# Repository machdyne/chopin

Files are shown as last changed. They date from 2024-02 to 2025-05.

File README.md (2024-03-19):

# Chopin Motherboard

Chopin is a host board that when paired with a [Sechzig](https://github.com/machdyne/sechzig) compute module can function as a development board.

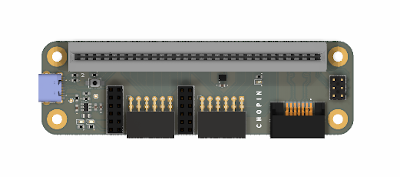
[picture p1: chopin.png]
Chopin


This repo contains schematics, PCB layouts, pinouts and documentation.

Find more information on the [Chopin product page](https://machdyne.com/product/chopin-motherboard/).

## Using Chopin

Chopin requires a Sechzig module to function. **When inserting a Sechzig module, make sure that pin 2 on Chopin and pin 2 on the module are both on the same side.**

## Programming

Chopin has a JTAG header that when paired with a JTAG programmer, can be used to program Sechzig modules. The following examples assume you're using a USB Blaster JTAG programmer.

Program the configuration SRAM of a Sechzig module:

```
sudo openFPGALoader -c usb-blaster image.bit
```

Program the configuration flash on a Sechzig module:

```
sudo openFPGALoader -f -c usb-blaster image.bit
```

## Pinouts

### JTAG Header

The 3.3V JTAG header can be used to program the Sechzig module. It can also be used to provide power (5V) to the board.

```
6 5
4 3
2 1
```

| Pin | Signal |
| --- | --- |
| 1 | TCK |
| 2 | TDI |
| 3 | TDO |
| 4 | TMS |
| 5 | 5V0 |
| 6 | GND |

### LVDS Port

Chopin has an experimental SATA-style LVDS port. SATA is not supported.

| Pin | Signal |
| --- | --- |
| 1 | GND |
| 2 | DS2\_P |
| 3 | DS2\_N |
| 4 | GND |
| 5 | DS1\_P |
| 6 | DS1\_N |
| 7 | GND |

## Funding

This project was partially funded through the NGI0 Entrust Fund, a fund established by NLnet with financial support from the European Commission's Next Generation Internet programme.

## License

This project is released under the [CERN-OHL-P](LICENSE.txt) license.

Note: You can use these designs for commercial purposes but we ask that instead of producing exact clones, that you either replace our trademarks and logos with your own or add your own next to ours.

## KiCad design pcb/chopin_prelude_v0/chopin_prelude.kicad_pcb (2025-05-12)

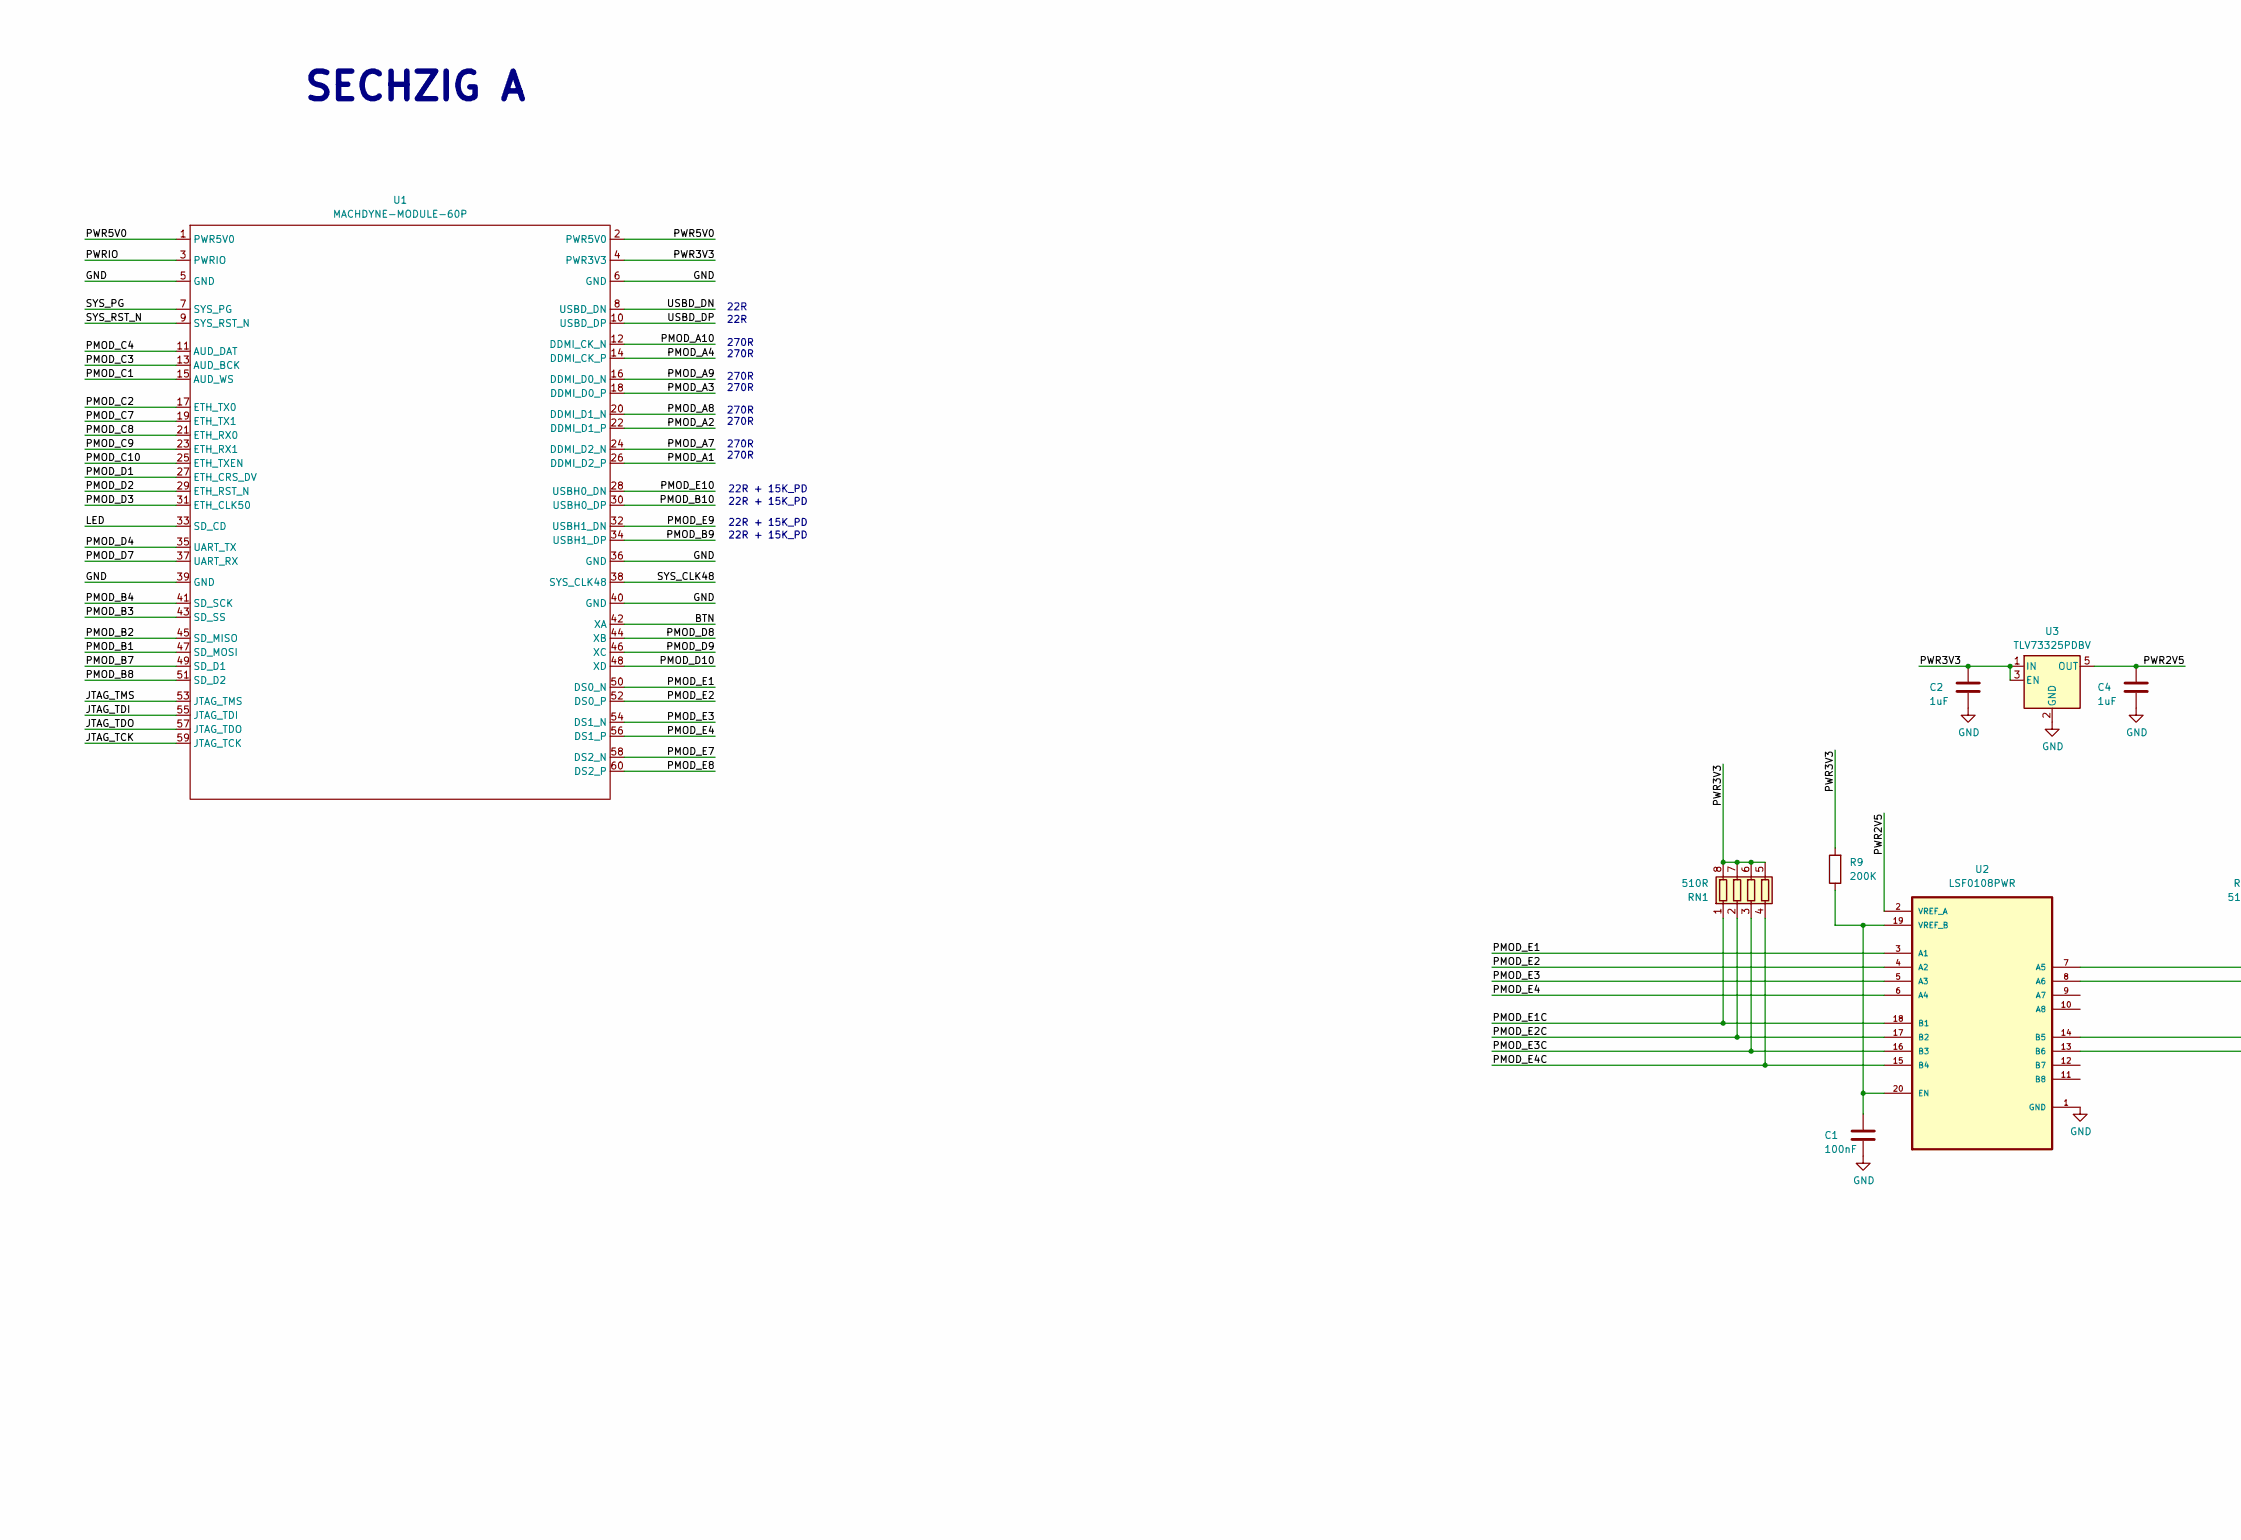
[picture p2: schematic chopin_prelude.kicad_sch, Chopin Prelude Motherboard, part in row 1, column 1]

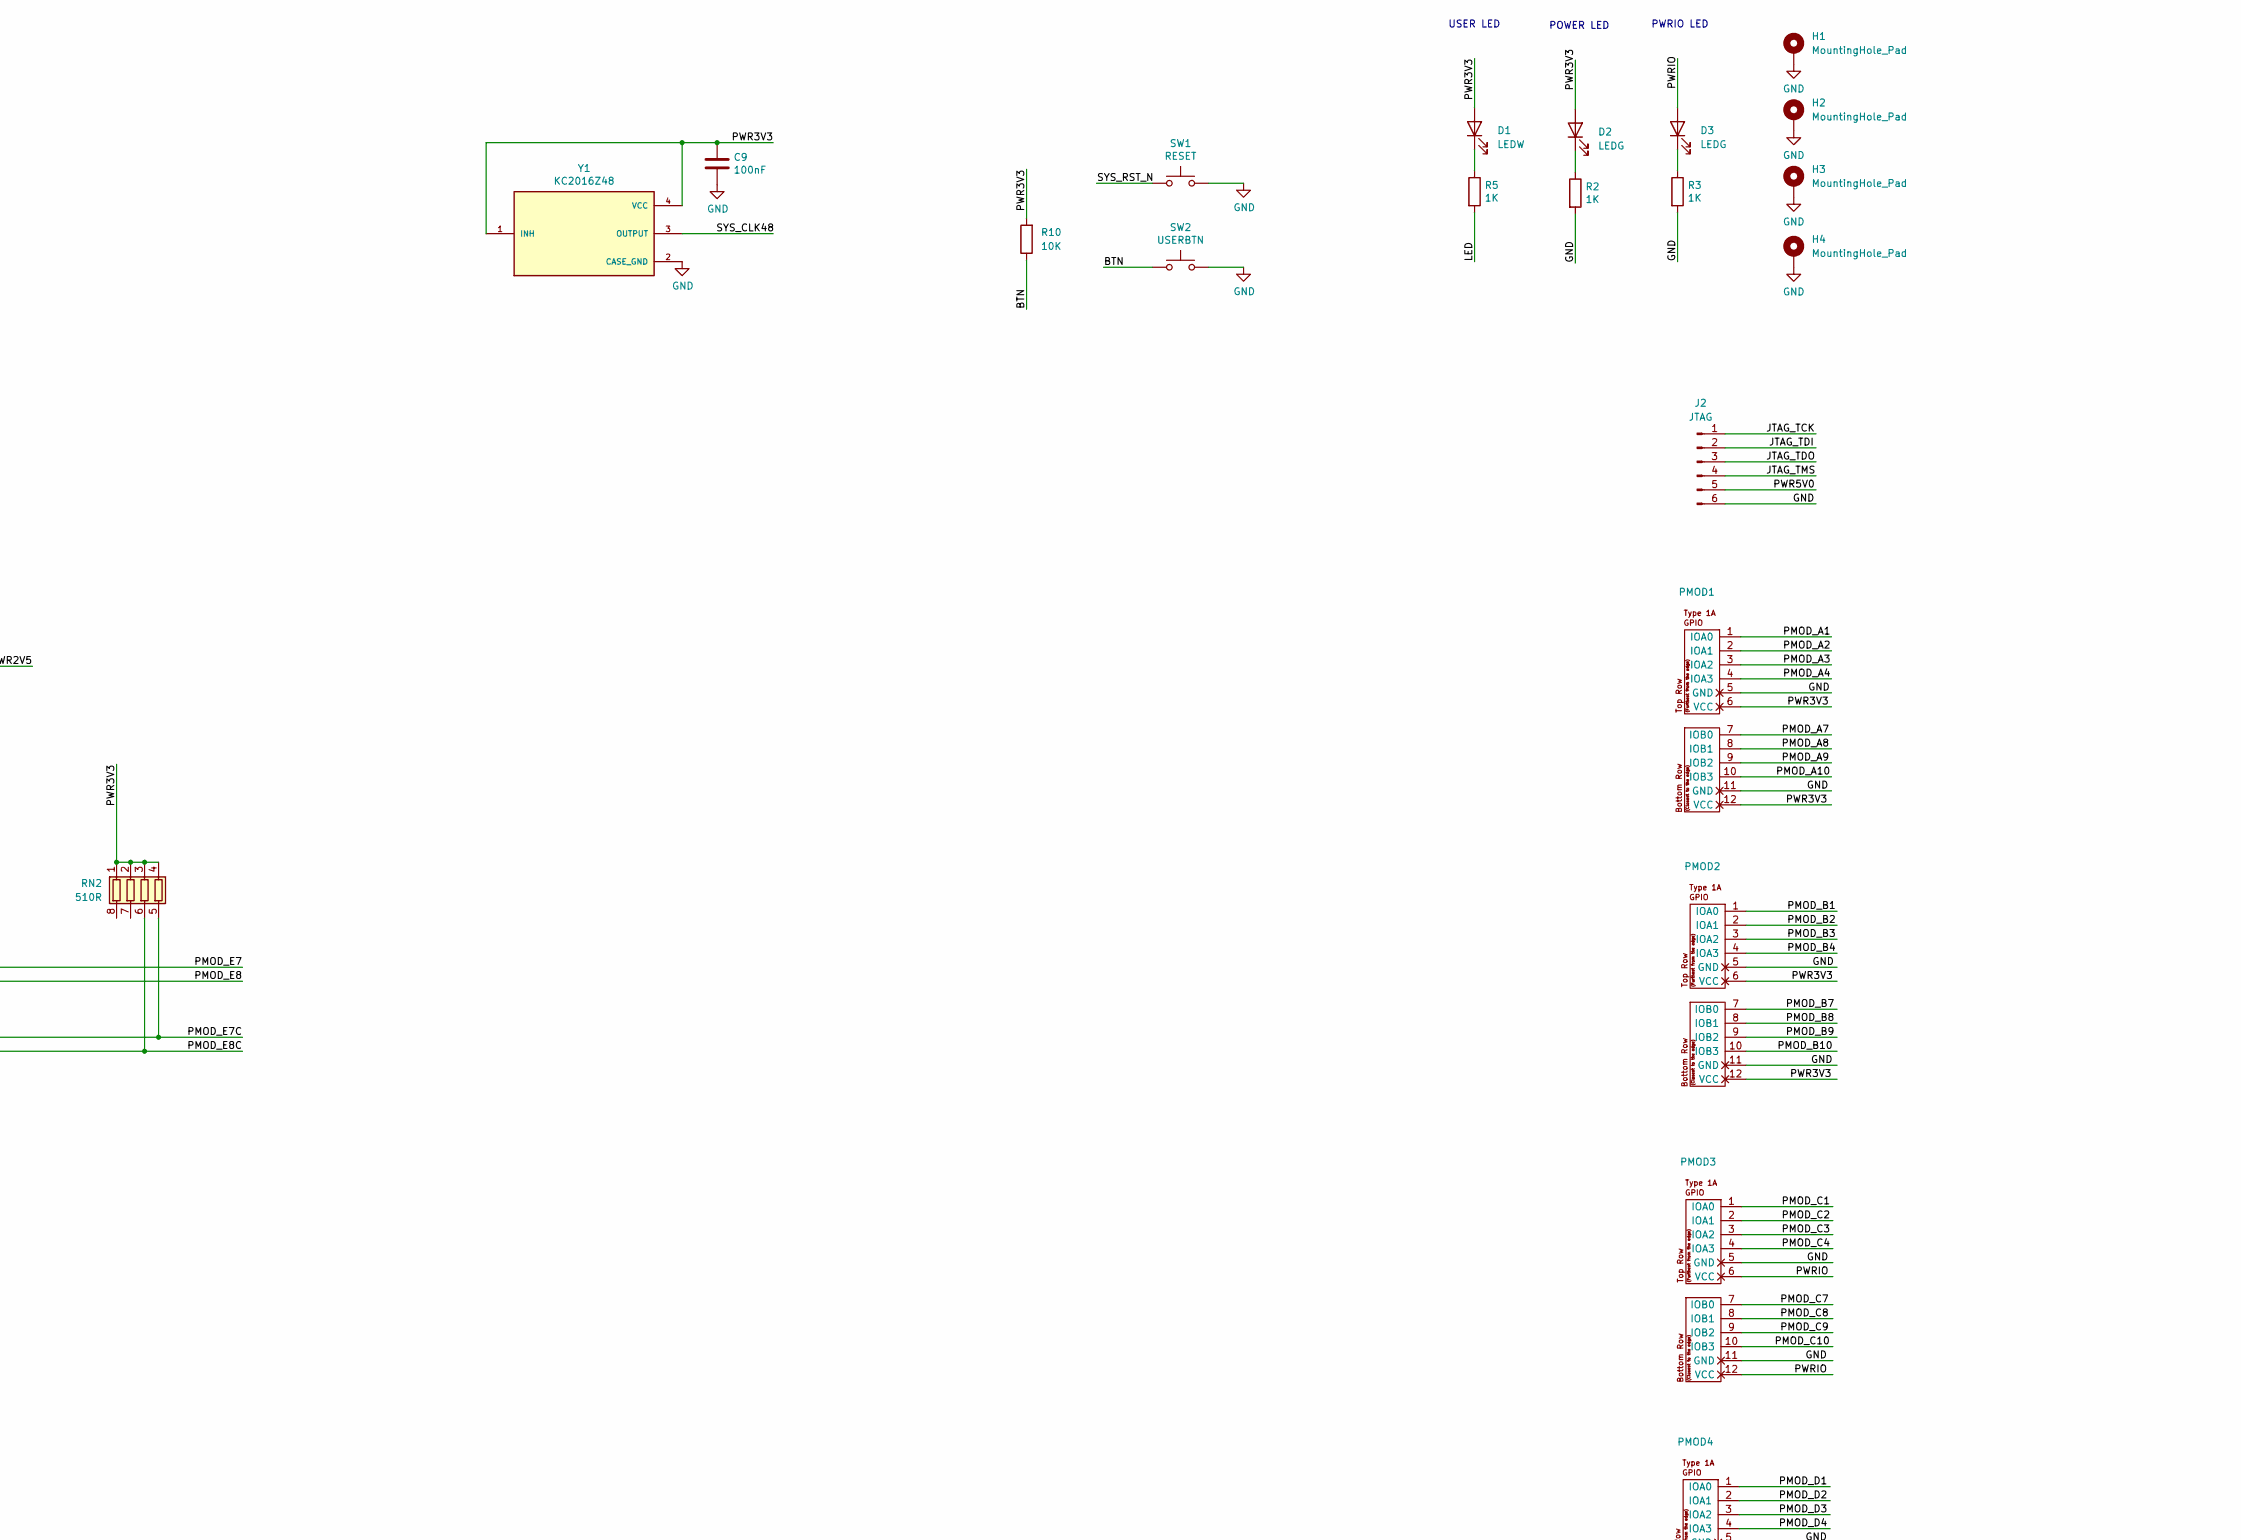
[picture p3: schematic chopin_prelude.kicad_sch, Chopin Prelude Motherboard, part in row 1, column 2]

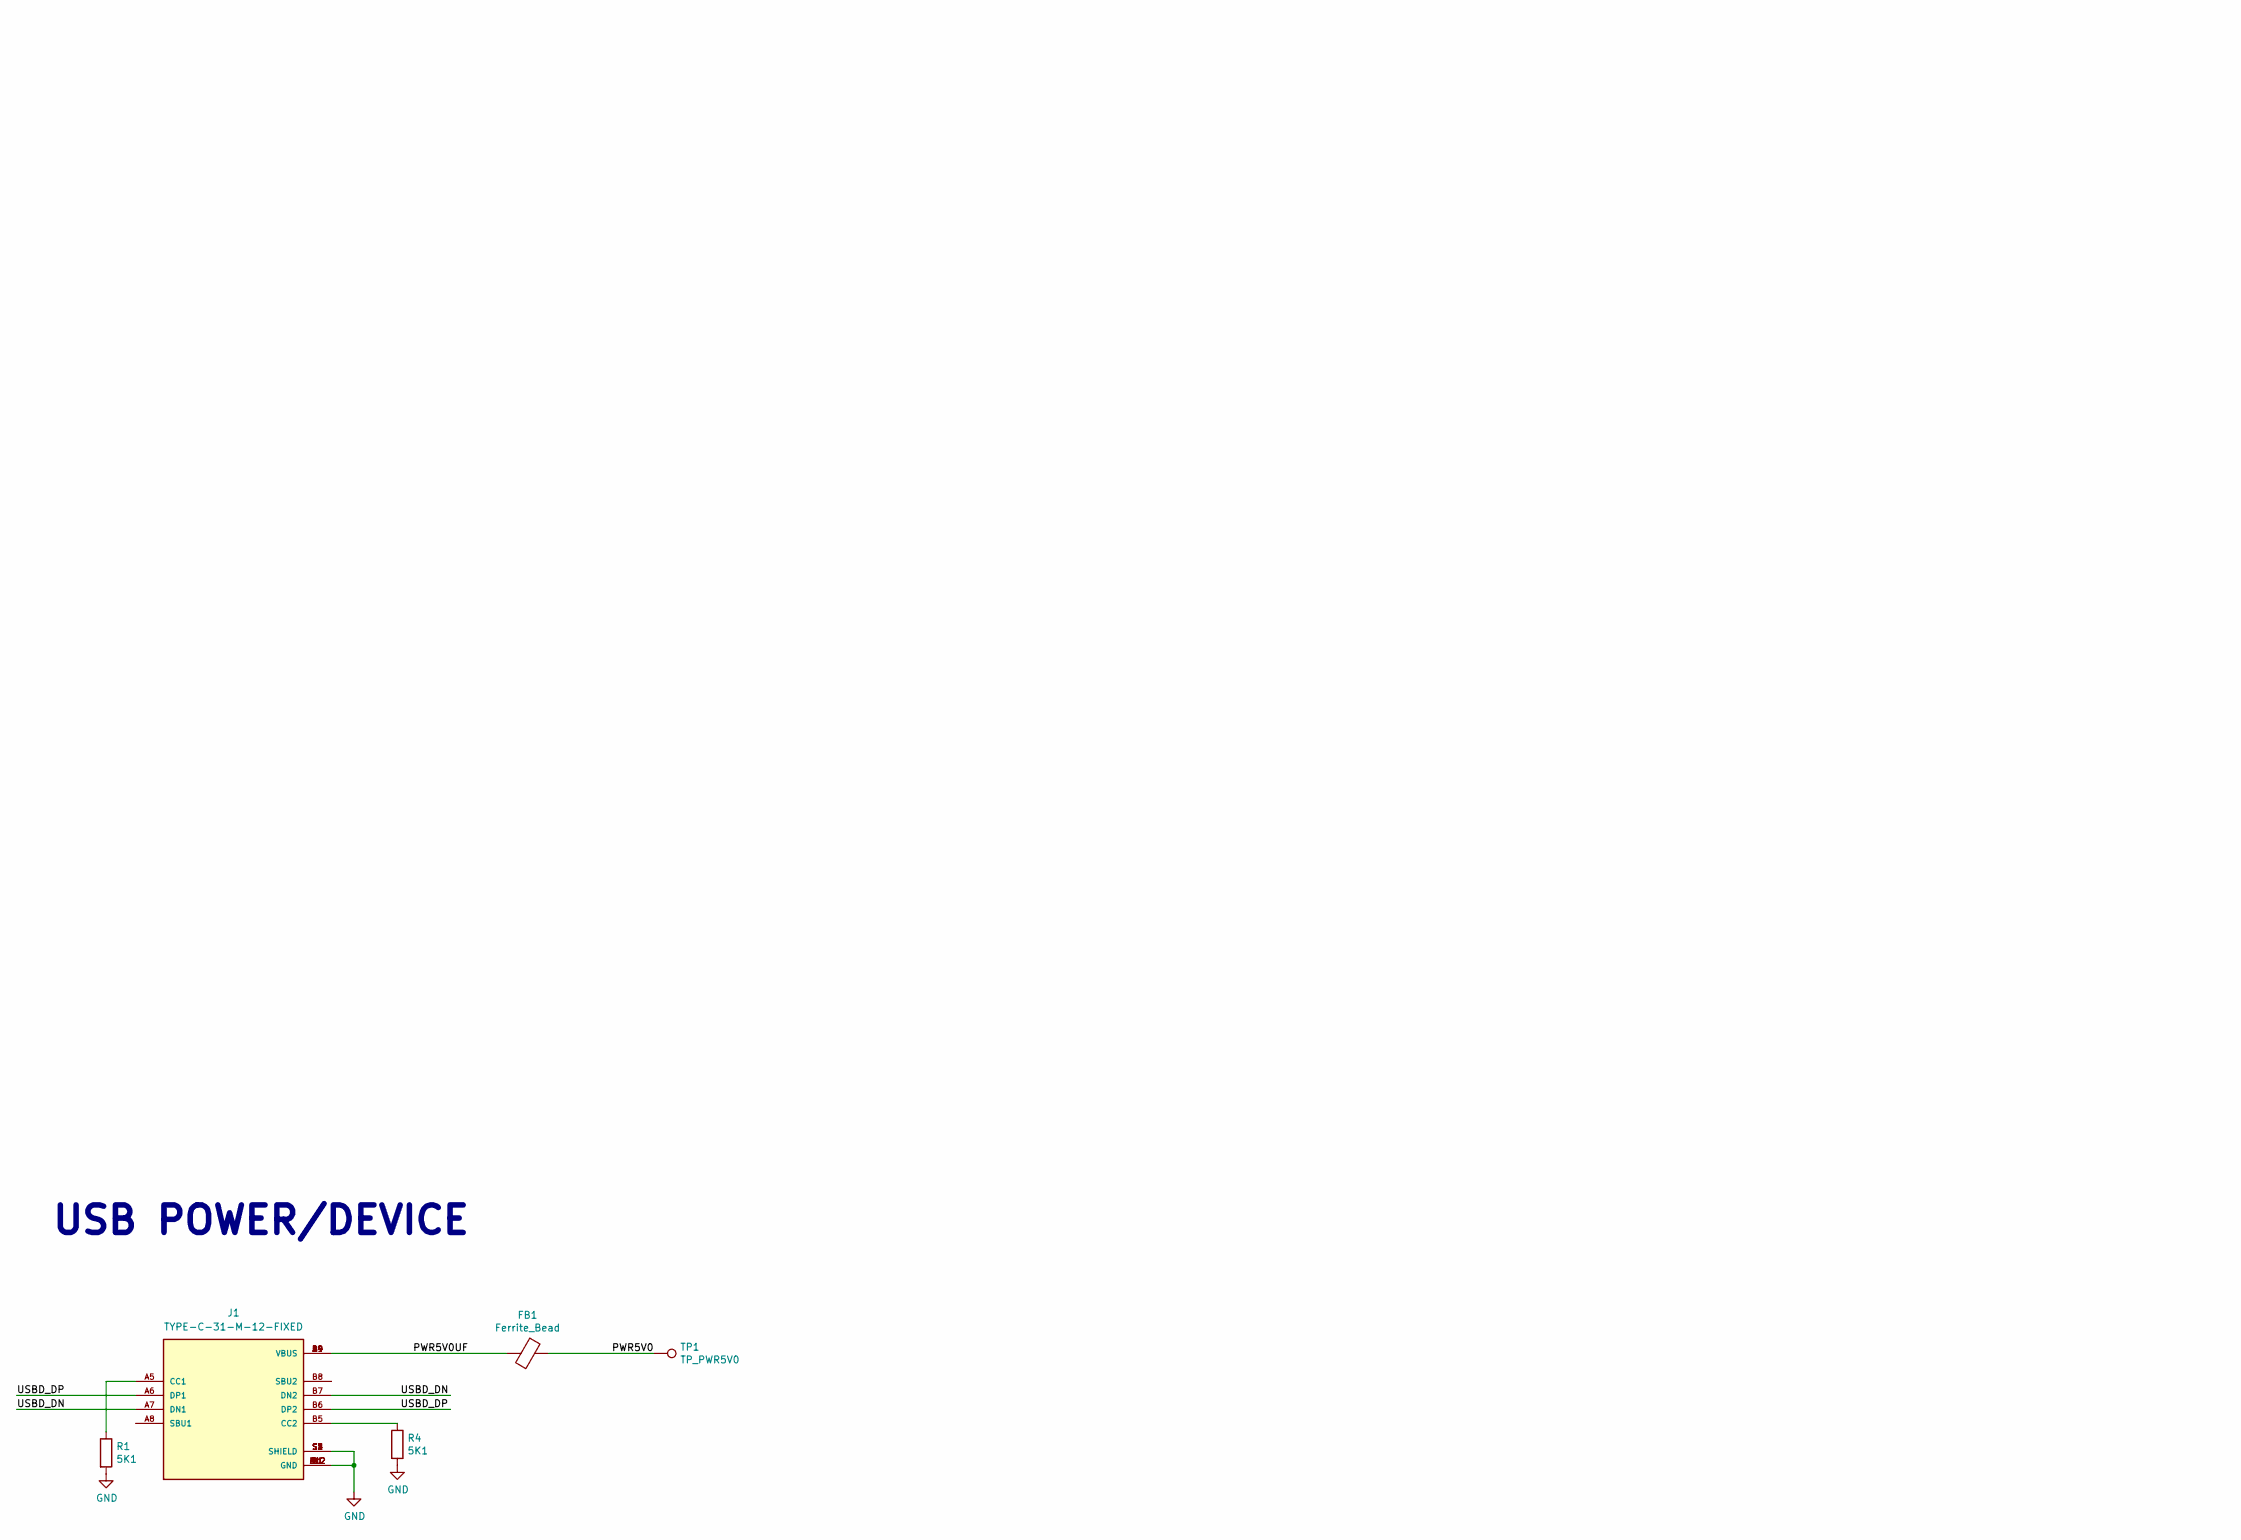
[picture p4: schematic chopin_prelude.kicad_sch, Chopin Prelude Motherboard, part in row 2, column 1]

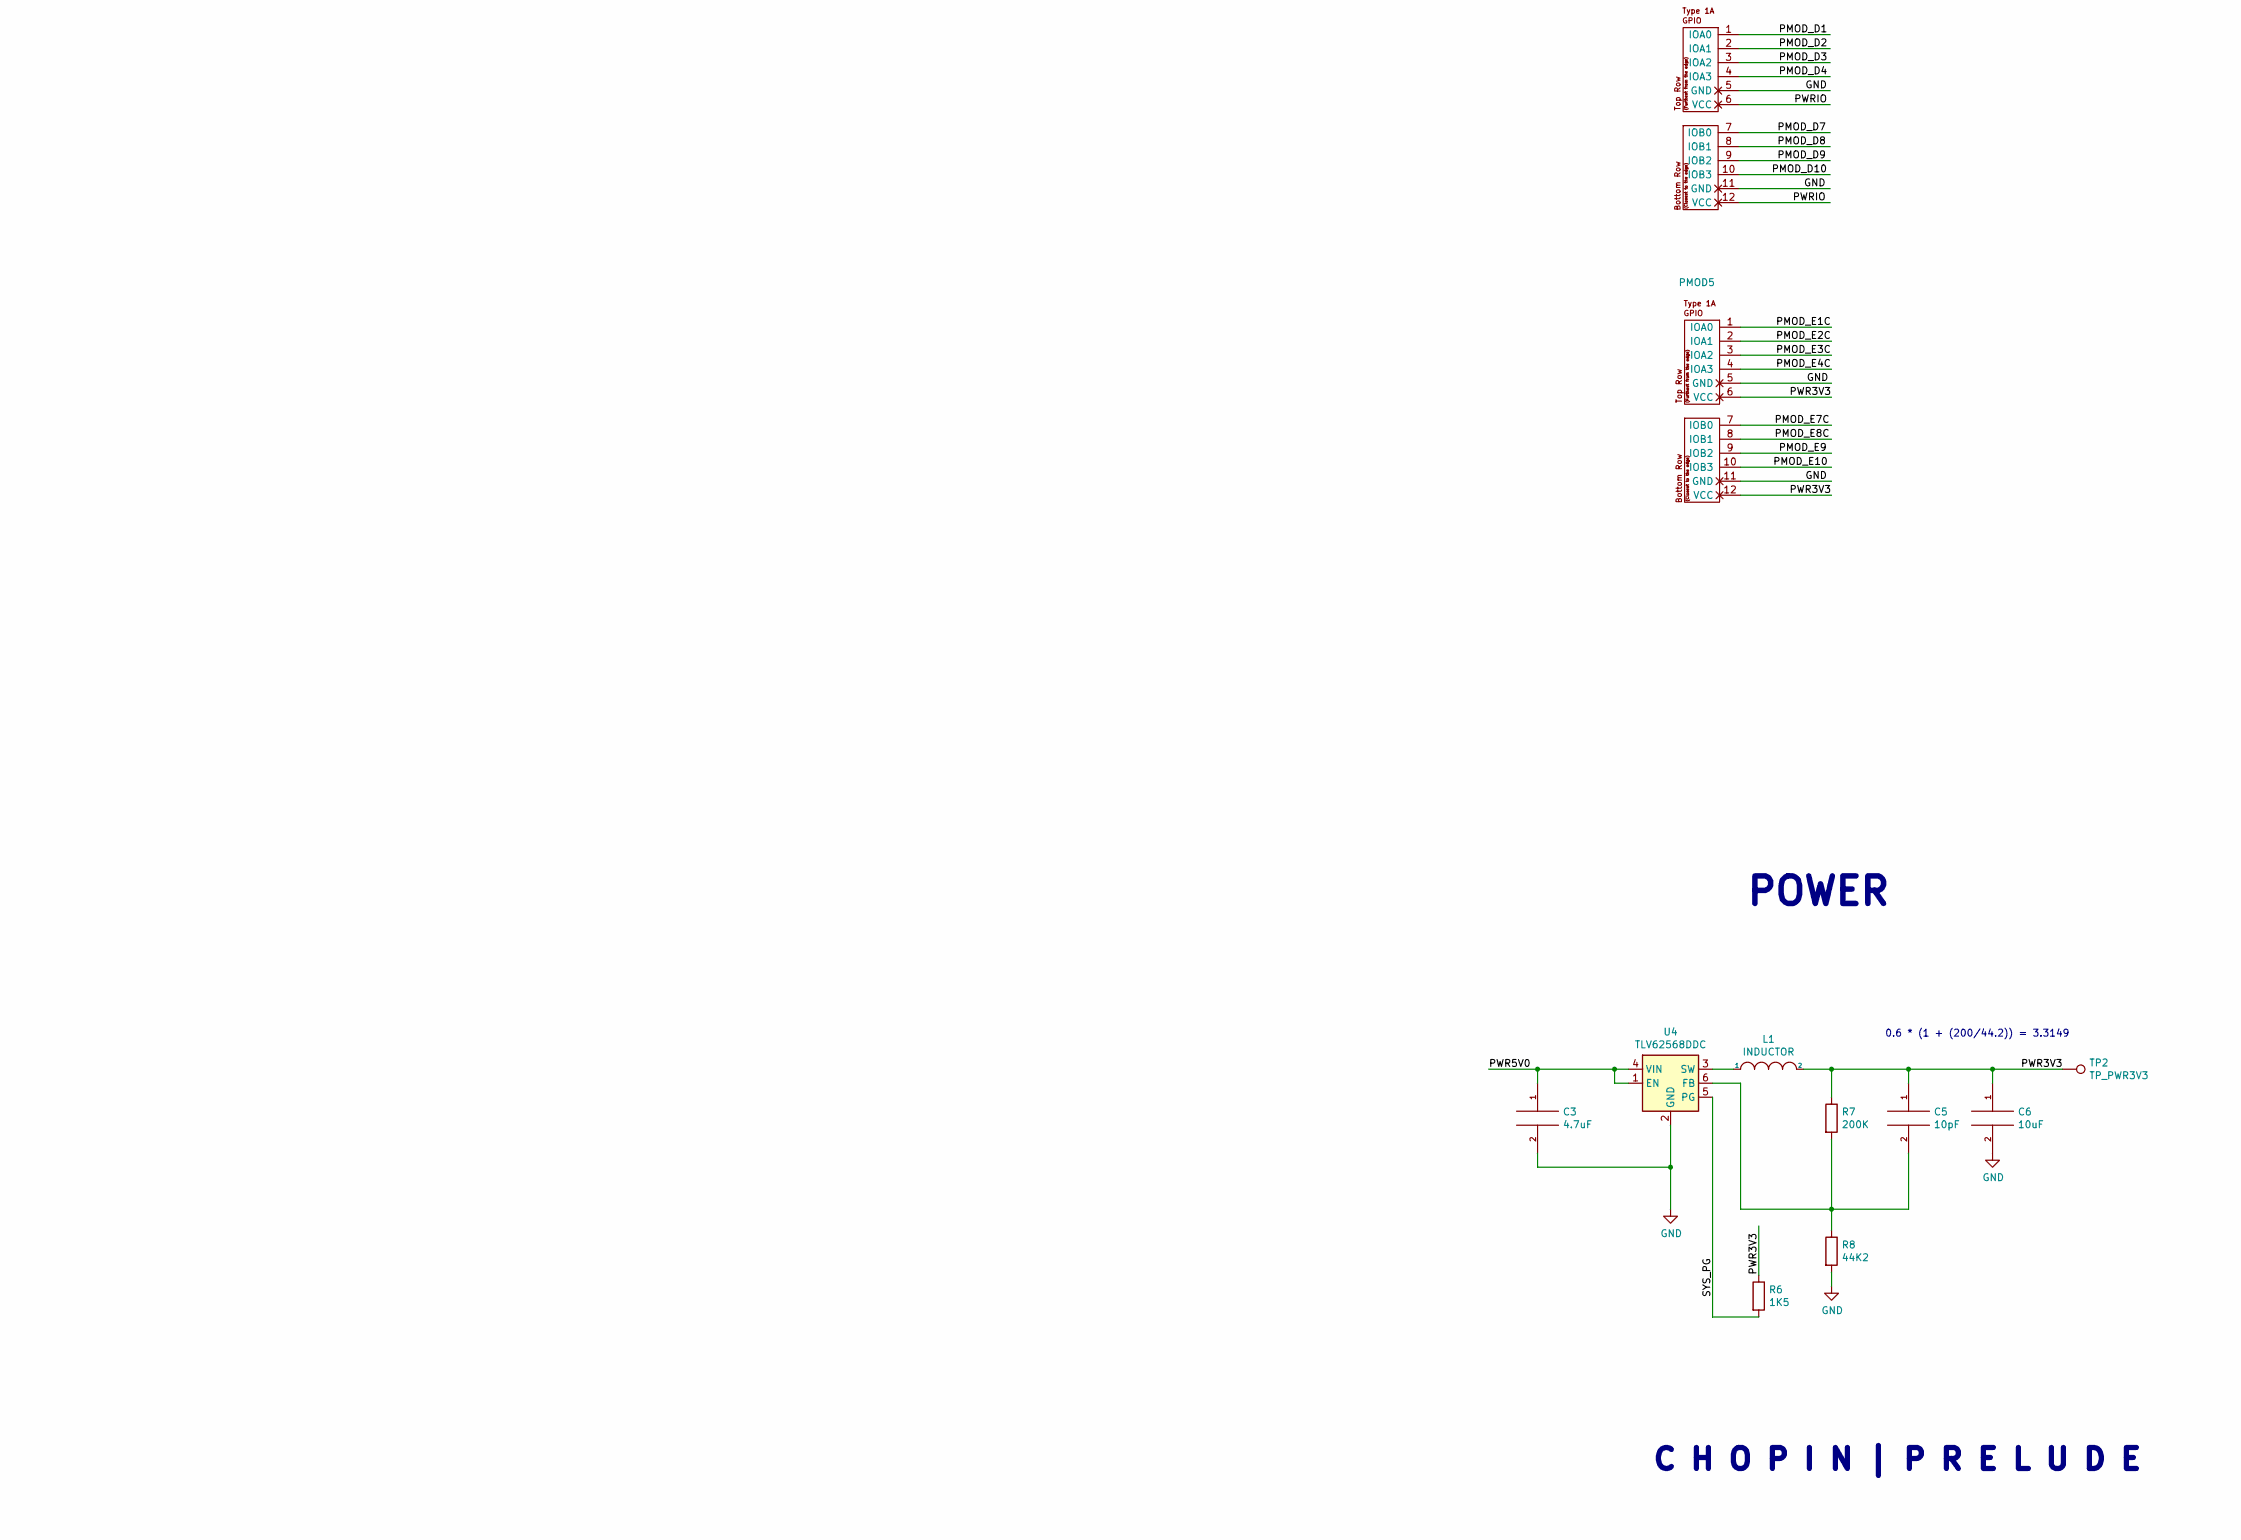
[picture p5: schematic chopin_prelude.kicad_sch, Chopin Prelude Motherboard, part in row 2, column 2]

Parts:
C1: 100nF; C_0402_1005Metric
C2, C4: 1uF; C_0402_1005Metric
C3: 4.7uF; C_0603_1608Metric
C5: 10pF; C_0603_1608Metric
C6: 10uF; C_0603_1608Metric
C9: 100nF; C_0603_1608Metric
D1: LEDW; LED_0603_1608Metric
D2, D3: LEDG; LED_0603_1608Metric
FB1: Ferrite_Bead; R_0603_1608Metric
H1, H2, H3, H4: MountingHole_Pad; MountingHole_3.2mm_M3_Pad
J1: TYPE-C-31-M-12-FIXED; USB_C_Receptacle_HRO_TYPE-C-31-M-12-BIG-PADS; PARTREV A
J2: JTAG; PinHeader_2x03_P2.54mm_Vertical
L1: INDUCTOR; L_0805_2012Metric
PMOD1, PMOD2, PMOD5: PMOD-Device-x2-Type-1A-GPIO; PMOD_2x06_HOST
PMOD3, PMOD4: PMOD-Device-x2-Type-1A-GPIO; PMOD_2x06_HOST_VERTICAL
R1, R4: 5K1; R_0603_1608Metric
R2, R3, R5: 1K; R_0603_1608Metric
R6: 1K5; R_0603_1608Metric
R7: 200K; R_0603_1608Metric
R8: 44K2; R_0603_1608Metric
R9: 200K; R_0402_1005Metric
R10: 10K; R_0603_1608Metric
RN1, RN2: 510R; R_Array_Convex_4x0402
SW1: RESET; Button_2P_3x4mm
SW2: USERBTN; Kailh_Mute_6x6mm
TP1: TP_PWR5V0; TestPoint_THTPad_D1.0mm_Drill0.5mm
TP2: TP_PWR3V3; TestPoint_THTPad_D1.0mm_Drill0.5mm
U1: MACHDYNE-MODULE-60P; MACHDYNE_EDGE_SOCKET_60P
U2: LSF0108PWR; TSSOP-20_4.4x6.5mm_P0.65mm
U3: TLV73325PDBV; SOT-23-5
U4: TLV62568DDC; SOT-23-6
Y1: KC2016Z48; OSC_KC2016Z13.5600C1KX00; PARTREV November 2020

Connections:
/BTN: R10.1, SW2.1, U1.42 (XA)
/JTAG_TCK: J2.1, U1.59 (JTAG_TCK)
/JTAG_TDI: J2.2, U1.55 (JTAG_TDI)
/JTAG_TDO: J2.3, U1.57 (JTAG_TDO)
/JTAG_TMS: J2.4, U1.53 (JTAG_TMS)
/LED: R5.2, U1.33 (SD_CD)
/PMOD_A1: PMOD1.1 (IOA0), U1.26 (DDMI_D2_P)
/PMOD_A2: PMOD1.2 (IOA1), U1.22 (DDMI_D1_P)
/PMOD_A3: PMOD1.3 (IOA2), U1.18 (DDMI_D0_P)
/PMOD_A4: PMOD1.4 (IOA3), U1.14 (DDMI_CK_P)
/PMOD_A7: PMOD1.7 (IOB0), U1.24 (DDMI_D2_N)
/PMOD_A8: PMOD1.8 (IOB1), U1.20 (DDMI_D1_N)
/PMOD_A9: PMOD1.9 (IOB2), U1.16 (DDMI_D0_N)
/PMOD_A10: PMOD1.10 (IOB3), U1.12 (DDMI_CK_N)
/PMOD_B1: PMOD2.1 (IOA0), U1.47 (SD_MOSI)
/PMOD_B2: PMOD2.2 (IOA1), U1.45 (SD_MISO)
/PMOD_B3: PMOD2.3 (IOA2), U1.43 (SD_SS)
/PMOD_B4: PMOD2.4 (IOA3), U1.41 (SD_SCK)
/PMOD_B7: PMOD2.7 (IOB0), U1.49 (SD_D1)
/PMOD_B8: PMOD2.8 (IOB1), U1.51 (SD_D2)
/PMOD_B9: PMOD2.9 (IOB2), U1.34 (USBH1_DP)
/PMOD_B10: PMOD2.10 (IOB3), U1.30 (USBH0_DP)
/PMOD_C1: PMOD3.1 (IOA0), U1.15 (AUD_WS)
/PMOD_C2: PMOD3.2 (IOA1), U1.17 (ETH_TX0)
/PMOD_C3: PMOD3.3 (IOA2), U1.13 (AUD_BCK)
/PMOD_C4: PMOD3.4 (IOA3), U1.11 (AUD_DAT)
/PMOD_C7: PMOD3.7 (IOB0), U1.19 (ETH_TX1)
/PMOD_C8: PMOD3.8 (IOB1), U1.21 (ETH_RX0)
/PMOD_C9: PMOD3.9 (IOB2), U1.23 (ETH_RX1)
/PMOD_C10: PMOD3.10 (IOB3), U1.25 (ETH_TXEN)
/PMOD_D1: PMOD4.1 (IOA0), U1.27 (ETH_CRS_DV)
/PMOD_D2: PMOD4.2 (IOA1), U1.29 (ETH_RST_N)
/PMOD_D3: PMOD4.3 (IOA2), U1.31 (ETH_CLK50)
/PMOD_D4: PMOD4.4 (IOA3), U1.35 (UART_TX)
/PMOD_D7: PMOD4.7 (IOB0), U1.37 (UART_RX)
/PMOD_D8: PMOD4.8 (IOB1), U1.44 (XB)
/PMOD_D9: PMOD4.9 (IOB2), U1.46 (XC)
/PMOD_D10: PMOD4.10 (IOB3), U1.48 (XD)
/PMOD_E1: U1.50 (DS0_N), U2.3 (A1)
/PMOD_E1C: PMOD5.1 (IOA0), RN1.1 (R1.1), U2.18 (B1)
/PMOD_E2: U1.52 (DS0_P), U2.4 (A2)
/PMOD_E2C: PMOD5.2 (IOA1), RN1.2 (R2.1), U2.17 (B2)
/PMOD_E3: U1.54 (DS1_N), U2.5 (A3)
/PMOD_E3C: PMOD5.3 (IOA2), RN1.3 (R3.1), U2.16 (B3)
/PMOD_E4: U1.56 (DS1_P), U2.6 (A4)
/PMOD_E4C: PMOD5.4 (IOA3), RN1.4 (R4.1), U2.15 (B4)
/PMOD_E7: U1.58 (DS2_N), U2.7 (A5)
/PMOD_E7C: PMOD5.7 (IOB0), RN2.5 (R4.2), U2.14 (B5)
/PMOD_E8: U1.60 (DS2_P), U2.8 (A6)
/PMOD_E8C: PMOD5.8 (IOB1), RN2.6 (R3.2), U2.13 (B6)
/PMOD_E9: PMOD5.9 (IOB2), U1.32 (USBH1_DN)
/PMOD_E10: PMOD5.10 (IOB3), U1.28 (USBH0_DN)
/PWR2V5: C4.1, U2.2 (VREF_A), U3.5 (OUT)
/PWR3V3: C2.1, C5.1, C6.1, C9.1, D1.2 (A), D2.2 (A), L1.2, PMOD1.6 (VCC), PMOD1.12 (VCC), PMOD2.6 (VCC), PMOD2.12 (VCC), PMOD5.6 (VCC), PMOD5.12 (VCC), R6.1, R7.1, R9.2, R10.2, RN1.5 (R4.2), RN1.6 (R3.2), RN1.7 (R2.2), RN1.8 (R1.2), RN2.1 (R1.1), RN2.2 (R2.1), RN2.3 (R3.1), RN2.4 (R4.1), TP2.1, U1.4 (PWR3V3), U3.1 (IN), U3.3 (EN), Y1.1 (INH), Y1.4 (VCC)
/PWR5V0: C3.1, FB1.1, J2.5, TP1.1, U1.1 (PWR5V0), U1.2 (PWR5V0), U4.1 (EN), U4.4 (VIN)
/PWR5V0UF: FB1.2, J1.A4 (VBUS), J1.A9 (VBUS), J1.B4 (VBUS), J1.B9 (VBUS)
/PWRIO: D3.2 (A), PMOD3.6 (VCC), PMOD3.12 (VCC), PMOD4.6 (VCC), PMOD4.12 (VCC), U1.3 (PWRIO)
/SYS_CLK48: U1.38 (SYS_CLK48), Y1.3 (OUTPUT)
/SYS_PG: R6.2, U1.7 (SYS_PG), U4.5 (PG)
/SYS_RST_N: SW1.1, U1.9 (SYS_RST_N)
/USBD_DN: J1.A7 (DN1), J1.B7 (DN2), U1.8 (USBD_DN)
/USBD_DP: J1.A6 (DP1), J1.B6 (DP2), U1.10 (USBD_DP)
GND: C1.2, C2.2, C3.2, C4.2, C6.2, C9.2, H1.1, H2.1, H3.1, H4.1, J1.A1 (GND), J1.A12 (GND), J1.B1 (GND), J1.B12 (GND), J1.S1 (SHIELD), J1.S2 (SHIELD), J1.S3 (SHIELD), J1.S4 (SHIELD), J2.6, PMOD1.5 (GND), PMOD1.11 (GND), PMOD2.5 (GND), PMOD2.11 (GND), PMOD3.5 (GND), PMOD3.11 (GND), PMOD4.5 (GND), PMOD4.11 (GND), PMOD5.5 (GND), PMOD5.11 (GND), R1.2, R2.2, R3.2, R4.2, R8.2, SW1.2, SW2.2, U1.5 (GND), U1.6 (GND), U1.36 (GND), U1.39 (GND), U1.40 (GND), U2.1 (GND), U3.2 (GND), U4.2 (GND), Y1.2 (CASE_GND)
unnamed: D1.1 (K), R5.1
unnamed: D2.1 (K), R2.1
unnamed: D3.1 (K), R3.1
unnamed: J1.A5 (CC1), R1.1
unnamed: J1.B5 (CC2), R4.1
unnamed: C1.1, R9.1, U2.19 (VREF_B), U2.20 (EN)
unnamed: C5.2, R7.2, R8.1, U4.6 (FB)
unnamed: L1.1, U4.3 (SW)

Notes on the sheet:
PWRIO LED
C H O P I N | P R E L U D E
0.6 * (1 + (200/44.2)) = 3.3149
USER LED
22R + 15K_PD
22R
POWER
SECHZIG A
POWER LED
270R 270R 270R 270R 270R 270R 270R 270R
USB POWER/DEVICE

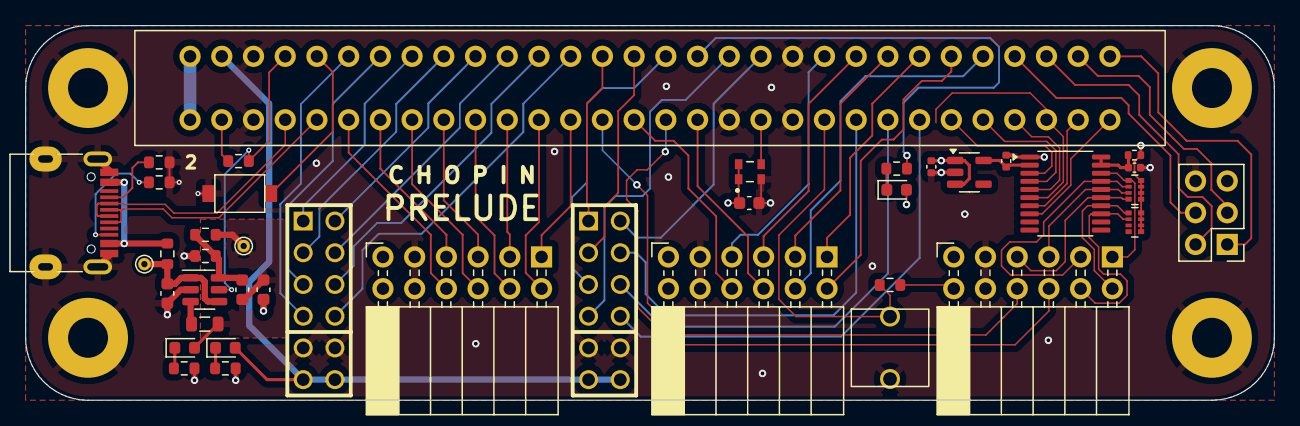
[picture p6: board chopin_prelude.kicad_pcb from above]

Board: 4 copper layers, 100.0 x 30.0 mm, 44 parts (0 on the bottom side), 71 nets.

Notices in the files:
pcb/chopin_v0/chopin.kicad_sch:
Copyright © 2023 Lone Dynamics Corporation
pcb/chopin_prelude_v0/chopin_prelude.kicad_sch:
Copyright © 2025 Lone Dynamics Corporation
